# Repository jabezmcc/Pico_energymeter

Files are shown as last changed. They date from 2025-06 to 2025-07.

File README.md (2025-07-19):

## Raspberry Pi Pico-based True Energy Meter for Appliances

This project couples a simple circuit with a Raspberry Pi Pico to capture the voltage and current waveforms of the power supplying any appliance, allowing a true, cycle-averaged measure of the power consumption.

The circuit uses a step-down transformer and a voltage divider to measure the voltage, and an Amploc current sensor to measure the current.  These signals are amplified and offset to the 0 - 3.3 V input range of the Pico ADCs.  Waveform data is captured over 3 cycles of the 60 Hz AC line supply, and the product of these is integrated.  Phase differences (as would happen with a motor), current spikes (within reason), etc, are automatically captured and integrated, so the measured  power is as correct as possible.

The Pico is programmed using MicroPython.  Voltages on the two ADCs are collected, the power is calculated, and the value is sent to an LCD display.  On a command from a host computer connected via USB, either the power value or a full 3-cycle waveform is transmitted for further processing and display.  The host code is written in Python, with a Qt6-based GUI that displays a chart of the power consumption vs. time, as well as numerical displays of the current power, the average power since starting acquisition, and the total energy consumed. 
 
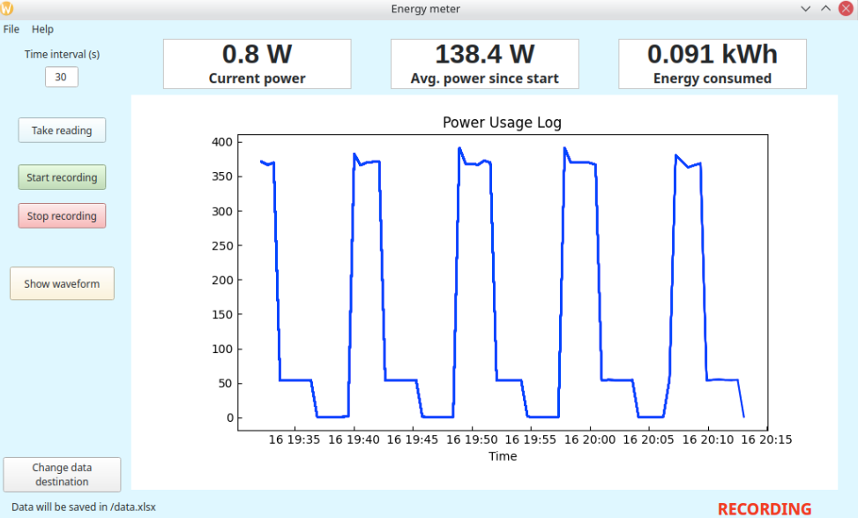
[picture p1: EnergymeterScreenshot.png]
Screenshot of dehumidifier energy consumption over about 40 min


#### Circuit description
AC power comes in via a male power receptacle and flows directly to the appliance via a female power socket. One of the wires carrying current passes through an [Amploc AMP25 current sensor](https://amploc.com/products/amp25-open-loop-hall-effect-sensor), which provides a 1.57 V to 3.42 V signal for currents from -25 A to +25 A.  The AC line voltage is also connected to a small step-down transformer producing 13.6 VAC.  I used something salvaged from an old phone system, but any small transformer that gets you down to below 20 V or so will work. 
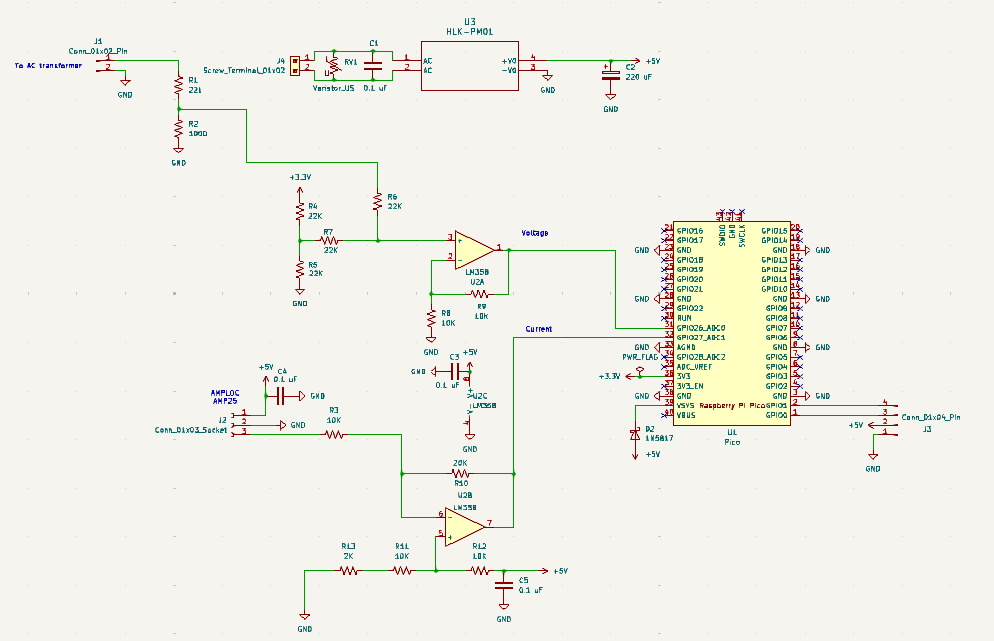
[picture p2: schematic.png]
Schematic of Pico Energymeter circuit

The voltage from the transformer is further divided down and offset using one of the op amps in a LM358 chip, and fed to ADC0 on the Pico.  The AMP25 output is similarly amplified and offset using the other half of the LM358 to match the ADC range, and fed to ADC1 on the Pico.  5 V power for the Pico, the AMP25, and the LM358 is provided by a small HLK-PM01 supply on board.  

#### Construction notes
Most of the circuit is on a circuit board, detailed in this [KiCAD file](./Pico_energymeter_v2.kicad_pro).
  
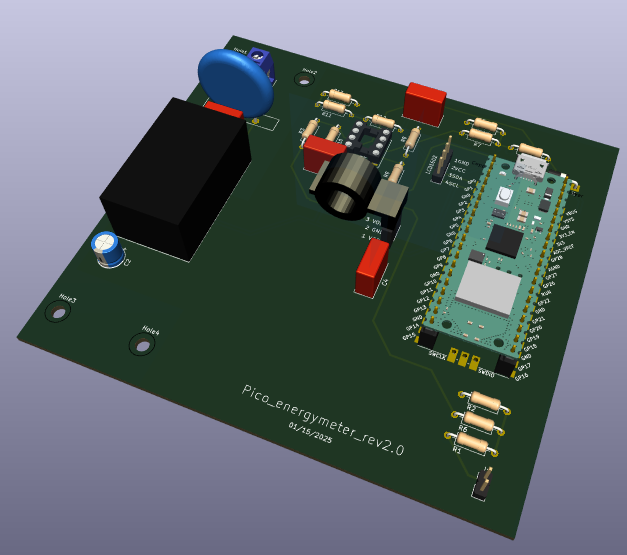
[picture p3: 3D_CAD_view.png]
3D CAD view
  

Everything is mounted in a plastic box, with the LCD 1602 display mounted in the lid. The display mount uses a home-made 3D-printed bezel (step file [here](./LCD1602bezel.step)). A short microUSB extender cable is used to bring the Pico's USB connection to a socket on the box wall.

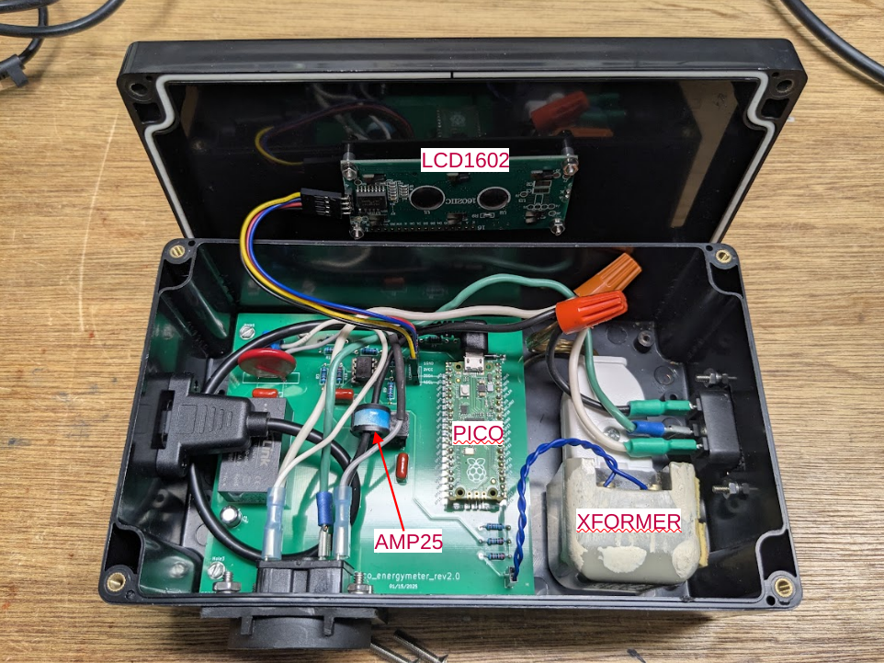
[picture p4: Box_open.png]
Box, open
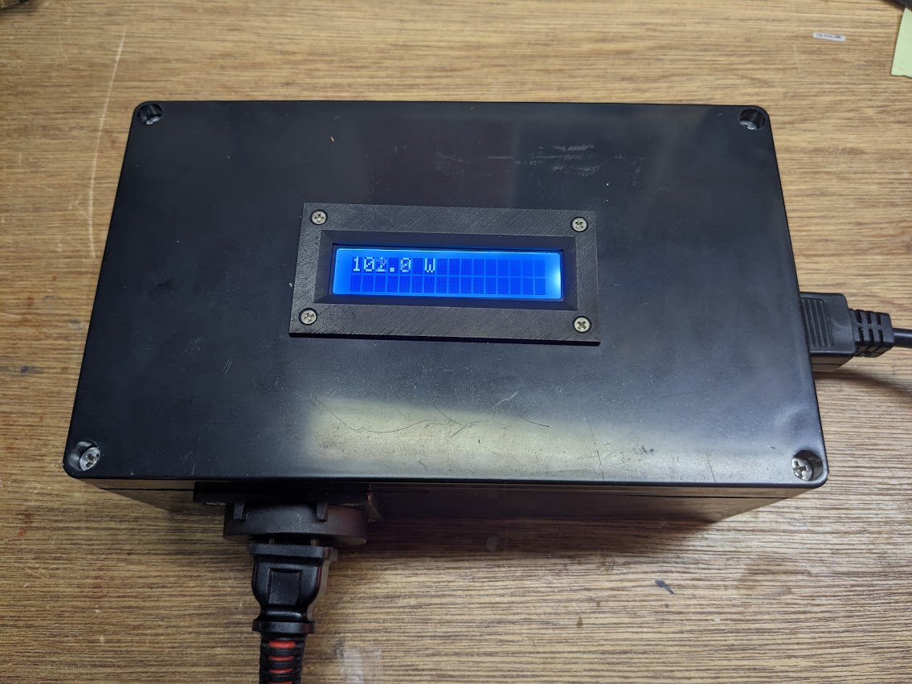
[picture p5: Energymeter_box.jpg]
Bax, closed
  

#### Pico code

The MicroPython code that runs on the Pico is contained in the file `powmon_picocode.py`.  This needs to be saved on the Pico as `main.py`.  The code makes use of a LCD1602 I2C Python library (of which there are many) downloaded from [https://github.com/liyuanhe211/Micropython_LCD1602_LCD2004_I2C_Lib](https://github.com/liyuanhe211/Micropython_LCD1602_LCD2004_I2C_Lib).  The file `lib_lcd1602_2004_with_i2c.py` from that site is included here under the name `lyhlcd1602.py`, and must also be stored on the Pico.  The easiest way to put these files on the Pico is by using [Thonny](https://thonny.org/).  

The code does the usual setup for LED, I2C, etc and sets up arrays for voltage and current measurements with 801 points each.  The nominal time between points for 3 cycles of 60 Hz is 3/60/801 =  62.42 $`\mu`$s.  However, there will be inherent small delays so it is necessary to do a measurement to determine empirically how many $`\mu`$s to tell MicroPython to wait between each point in order to ensure exactly 3 cycles with 801 points.  The procedure for this is described below.  

The main while-loop of the code cycles every 0.1 sec.  On each cycle it reads 801 points from the ADCs and calculates the power by multiplying the voltage and the current and integrating via Simpson's rule. The result is multiplied by a calibration factor determined as described below.  

On each cycle the code also reads two bytes from the USB serial port.  These two bytes represent requests from the host code.  If `b'po'` is transmitted this is a request for a power measurement, and the Pico code sends back a string version of the most recent power measurement.  If `b'wa'` is transmitted this is a request for the waveform, and the Pico code does a fresh measurement of the ADCs, packs the data bytes into a structure using `struct.pack()` and transmits these back to the host via `sys.stdout.buffer.write()`.

#### Host code
The host code `energymeter.py` was developed on a Linux system using Python 3.13.3.  I recommend using `pyenv` to set up a virtual environment specifying this version of Python to run it.  The required libraries are listed in `requirements.txt` and can be installed via `pip install requirements.txt`. The code should be fairly easily ported to Windows or MacOS with a few minor adjustments.  Usage should be pretty self explanatory:  click "Take reading" to get a measure of the power, click "Start recording" to begin logging the power, and click "Stop recording" when you want to stop. You will be asked whether you want to save the data.  Click "Show waveform" if you want to see what the voltage and current waveforms look like, and click "Change data destination" if you want to save the data somewhere other than the default location. 
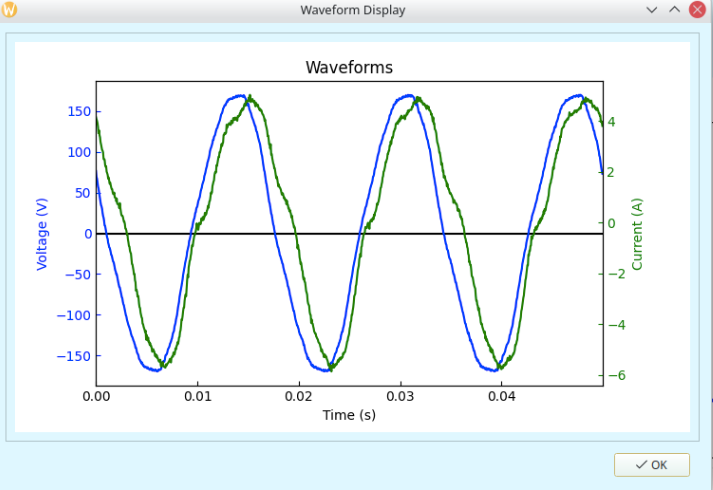
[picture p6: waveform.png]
Screenshot of waveform collected from a dehumidifier with fan and compressor running


#### Set up and Calibration

1. Timing

In order to make sure we get exactly three cycles of 60 Hz when `ndata` points are acquired, we need to find out how long the Pico takes to measure one data point and then add just enough time to equal `3/60/ndata`. This is done with a separate pair of Pico and host programs.  The program `powmon_picocode_get_base_delay.py` is run on the Pico by loading it into Thonny, pressing run, and then exiting Thonny.  Then the host code `Read_pico_find_dt.py` is run on the host computer.  The host code requests a waveform, the Pico code acquires 801 data points without any extra delay between points, and the voltage waveform is uploaded to the host computer.  An optimizer is then run to fit the waveform to a 60 Hz sine wave with the time interval between points, the amplitude and the phase as free parameters. The time interval resulting from this three-parameter fit is the base delay of the Pico.  This is compared to the time interval necessary to get exactly 3 cycles of 60 Hz, and the difference is reported. Measurements on my system indicate a delay of 12 $`\mu`$s  is required, and that is the value that is hard-coded in the main Pico code `powmon_picocode.py`.  If a value different from 12 $`\mu`$s is observed, the main Pico code should be edited and the definition of the constant `delay_us` changed.     

2. Calibration

Because the ADCs in the Pico measure on a scale of 0 to 65535, it is necessary to do an initial measurement to set the correct scaling factor for the voltage, current and power values.  To do this, a 100 W light bulb is plugged into the box and the actual RMS voltage and current are measured with a multimeter. Voltage is read by touching the hot terminals, and current is measured on the 10 A AC scale with the multimeter in the circuit. Of course ***this must be done with great care*** to avoid getting shocked! The light bulb is assumed to be a fully resistive load, so separate measurements of the voltage and current RMS values can be multiplied to obtain the RMS power.  

Once the RMS voltage and current are known for the 100 W light bulb, the correct scaling factors are determined by running another host program, `calibration.py`, on the host while the normal Pico code `powmon_picocode.py` is running on the Pico.  The RMS voltage and current as determined above are entered, then 'Measure' is pressed.  The power is then measured 20 times at 1 second intervals and the average calculated based on whatever scaling value is hard-coded in `powmon_picocode.py`.  The ratio of the actual RMS power to this measured value is reported as a correction factor that needs to be applied to the scaling factor by editing the definition of the constant `powfact` in  `powmon_picocode.py`.

The voltage and current scale factors are obtained by pressing the 'Measure waveform' button.  Three-cycle waveforms for voltage and current  are retrieved from the Pico and least-squares-fit to a sine wave with amplitude and phase as free parameters.  The scale factors necessary to match the amplitudes to $\sqrt2$ times the RMS values are then reported.  The main code `energymeter.py` should then be edited and the constants `voltfact` and  `curfact` set to these values. Note these values are only used when displaying the waveforms.  The power measurement has a separate scale factor stored in the Pico code.

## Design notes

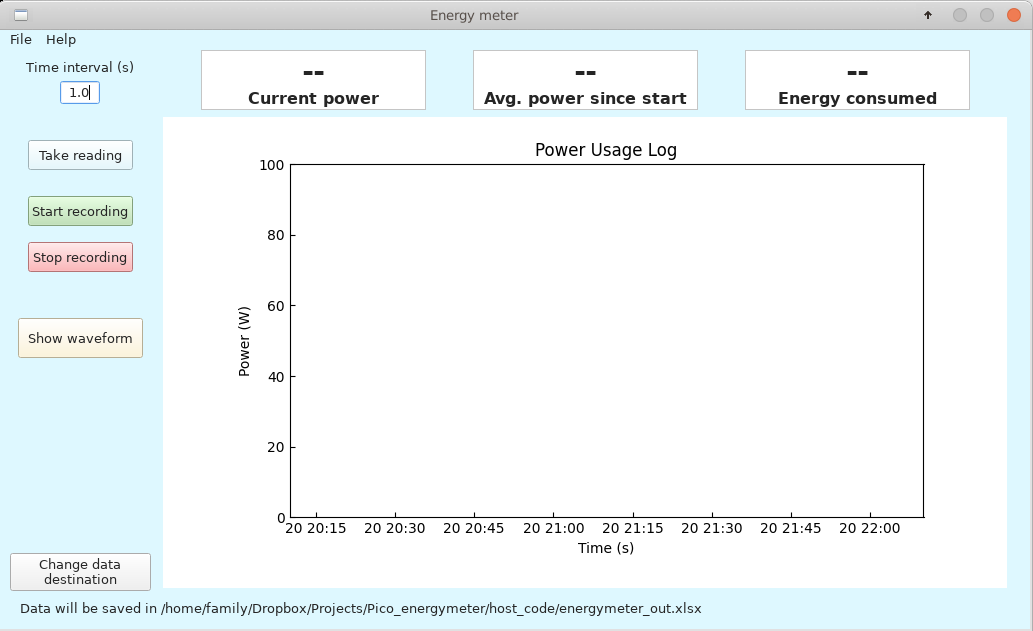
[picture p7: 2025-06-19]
Hostcode_screenshot.png

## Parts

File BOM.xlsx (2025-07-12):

Reference | Value
C1,C3,C4,C5 | 0.1 uF polyester film capacitor or equiv.
C2 | 220 uF electrolytic capacitor
D2 | 1N5817 Schottky diode
J1 | 01x02 male header
J2 | 01x03 female header
J3 | 01x04 male header
J4 | Screw_Terminal_01x02
R1 | 22k resistor
R2 | 1K resistor
R3,R8,R9,R11,R12 | 10K resistor
R4,R5,R6,R7 | 22K resistor
R10 | 20K resistor
R13 | 2K resistor
RV1 | Varistor, 160 V
U1 | Raspberry Pi Pico
U2 | LM358
U3 | HLK-PM01 115VAC to 5VDC power supply
Display | Freenove LCD 1602 display
Current sensor | Amploc AMP25 current sensor
Transformer | Transformer, 13.6 VAC
Cable | microUSB extender, e.g Poyiccot Micro USB Extension Cable, 90 Degree Right Angle Micro USB Male to Micro USB Female Power Extension Panel Mount Type Cable for Data & Charge
Output socket | female AC socket
Input socket | male AC power socket
Box | Junction Box, Zulkit Project Box IP65 Waterproof Outdoor Box ABS Plastic Electrical Boxes Electronic Enclosure Black 7.9 x 4.7 x 2.95 inch (200 x 120 x 75mm)
Bezel | 3D printed per stp file

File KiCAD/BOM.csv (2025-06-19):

Reference | Value | Datasheet | Footprint | Qty | DNP
C1,C3,C4,C5 | 0.1 uF | ~ | Capacitor_THT:C_Rect_L10.3mm_W4.5mm_P7.50mm_MKS4 | 4
C2 | 220 uF | ~ | Capacitor_THT:CP_Radial_D6.3mm_P2.50mm | 1
D2 | 1N5817 | http://www.vishay.com/docs/88525/1n5817.pdf | Diode_THT:D_DO-41_SOD81_P10.16mm_Horizontal | 1
J1 | Conn_01x02_Pin | ~ | Connector_PinHeader_2.54mm:PinHeader_1x02_P2.54mm_Vertical | 1
J2 | Conn_01x03_Socket | ~ | Connector_PinSocket_2.54mm:PinSocket_1x03_P2.54mm_Vertical | 1
J3 | Conn_01x04_Pin | ~ | Connector_PinHeader_2.54mm:PinHeader_1x04_P2.54mm_Vertical | 1
J4 | Screw_Terminal_01x02 | ~ | TerminalBlock:TerminalBlock_bornier-2_P5.08mm | 1
R1 | 22k | ~ | Resistor_THT:R_Axial_DIN0207_L6.3mm_D2.5mm_P10.16mm_Horizontal | 1
R2 | 1000 | ~ | Resistor_THT:R_Axial_DIN0207_L6.3mm_D2.5mm_P10.16mm_Horizontal | 1
R3,R8,R9,R11,R12 | 10K | ~ | Resistor_THT:R_Axial_DIN0207_L6.3mm_D2.5mm_P10.16mm_Horizontal | 5
R4,R5,R6,R7 | 22K | ~ | Resistor_THT:R_Axial_DIN0207_L6.3mm_D2.5mm_P10.16mm_Horizontal | 4
R10 | 20K | ~ | Resistor_THT:R_Axial_DIN0207_L6.3mm_D2.5mm_P10.16mm_Horizontal | 1
R13 | 2K | ~ | Resistor_THT:R_Axial_DIN0207_L6.3mm_D2.5mm_P10.16mm_Horizontal | 1
RV1 | Varistor_US | ~ | Varistor:RV_Disc_D21.5mm_W4.3mm_P10mm | 1
U1 | Pico |  | MCU_RaspberryPi_and_Boards:RPi_Pico_SMD_TH | 1
U2 | LM358 | http://www.ti.com/lit/ds/symlink/lm2904-n.pdf | Package_DIP:DIP-8_W7.62mm_Socket | 1
U3 | HLK-PM01 | HLK-PM01 | HLKPM01:DIP4_HLK-PM_HLK | 1

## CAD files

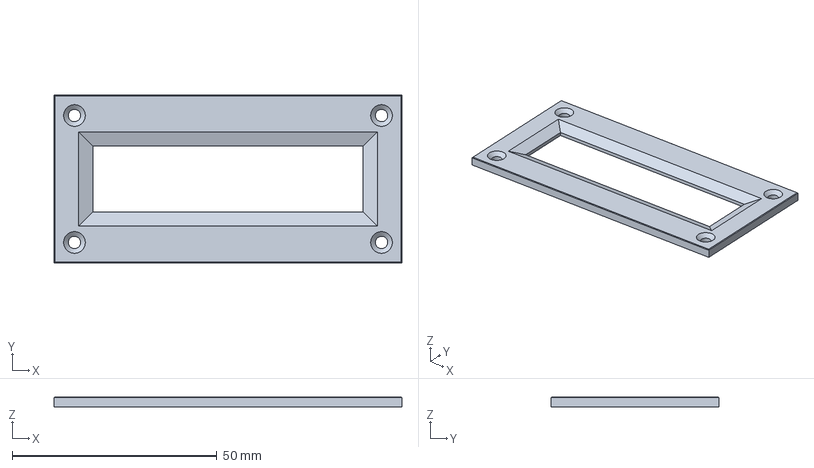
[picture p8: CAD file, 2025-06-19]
LCD1602bezel.step
85.0 x 41.0 x 2.50 mm

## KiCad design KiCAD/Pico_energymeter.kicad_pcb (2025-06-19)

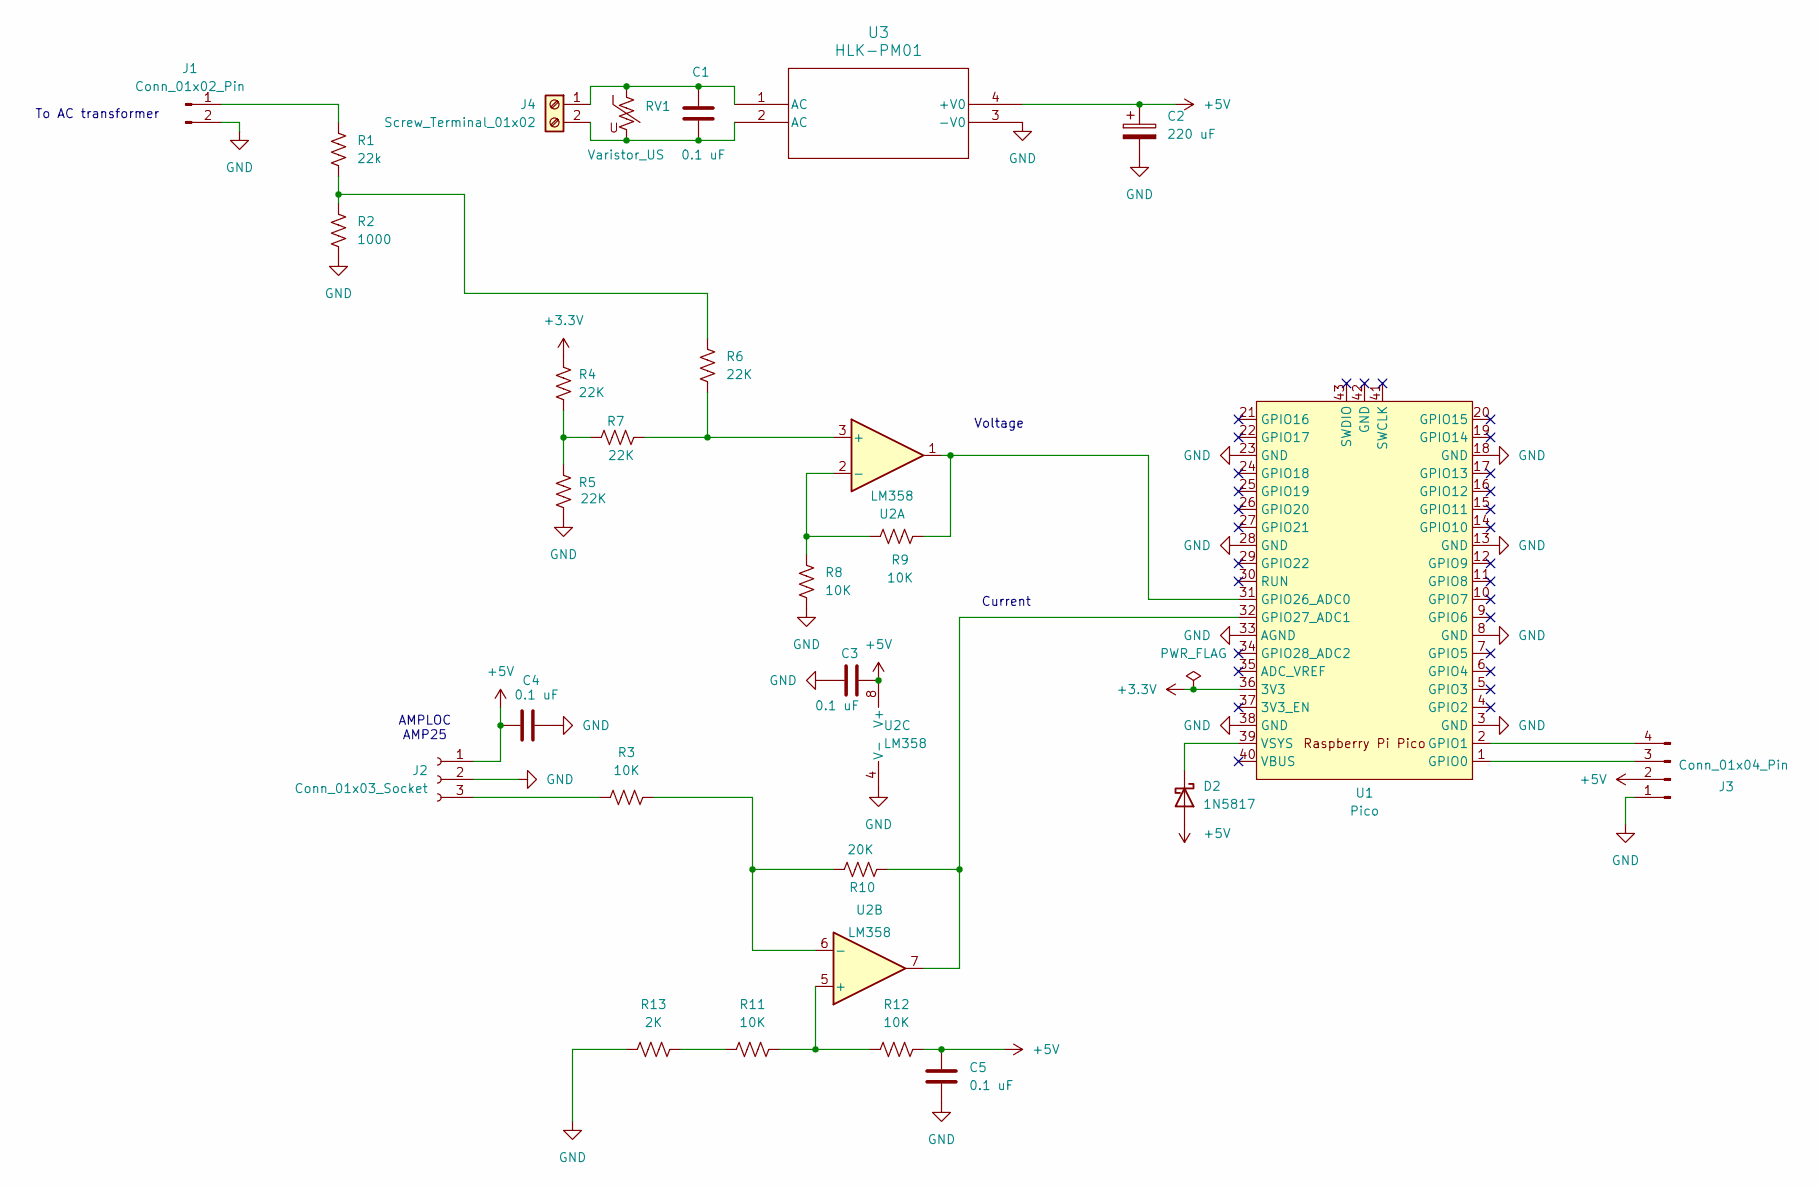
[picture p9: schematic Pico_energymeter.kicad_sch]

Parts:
C1, C3, C4, C5: 0.1 uF; C_Rect_L10.3mm_W4.5mm_P7.50mm_MKS4
C2: 220 uF; CP_Radial_D6.3mm_P2.50mm
D2: 1N5817; D_DO-41_SOD81_P10.16mm_Horizontal
J1: Conn_01x02_Pin; PinHeader_1x02_P2.54mm_Vertical
J2: Conn_01x03_Socket; PinSocket_1x03_P2.54mm_Vertical
J3: Conn_01x04_Pin; PinHeader_1x04_P2.54mm_Vertical
J4: Screw_Terminal_01x02; TerminalBlock_bornier-2_P5.08mm
R1: 22k; R_Axial_DIN0207_L6.3mm_D2.5mm_P10.16mm_Horizontal
R2: 1000; R_Axial_DIN0207_L6.3mm_D2.5mm_P10.16mm_Horizontal
R3, R8, R9, R11, R12: 10K; R_Axial_DIN0207_L6.3mm_D2.5mm_P10.16mm_Horizontal
R4, R5, R6, R7: 22K; R_Axial_DIN0207_L6.3mm_D2.5mm_P10.16mm_Horizontal
R10: 20K; R_Axial_DIN0207_L6.3mm_D2.5mm_P10.16mm_Horizontal
R13: 2K; R_Axial_DIN0207_L6.3mm_D2.5mm_P10.16mm_Horizontal
RV1: Varistor_US; RV_Disc_D21.5mm_W4.3mm_P10mm
U1: Pico; RPi_Pico_SMD_TH
U2: LM358; DIP-8_W7.62mm_Socket
U3: HLK-PM01; DIP4_HLK-PM_HLK

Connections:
+3.3V: R4.1, U1.36 (3V3)
+5V: C2.1, C3.2, C4.1, C5.1, D2.2 (A), J2.1, J3.2, R12.2, U2.8 (V+), U3.4 (+V0)
GND: C2.2, C3.1, C4.2, C5.2, J1.2, J2.2, J3.1, R2.2, R5.2, R8.2, R13.1, U1.3 (GND), U1.8 (GND), U1.13 (GND), U1.18 (GND), U1.23 (GND), U1.28 (GND), U1.33 (AGND), U1.38 (GND), U2.4 (V-), U3.3 (-V0)
unnamed: D2.1 (K), U1.39 (VSYS)
unnamed: J1.1, R1.1
unnamed: J2.3, R3.1
unnamed: J3.3, U1.1 (GPIO0)
unnamed: J3.4, U1.2 (GPIO1)
unnamed: C1.1, J4.1, RV1.1, U3.1 (AC)
unnamed: C1.2, J4.2, RV1.2, U3.2 (AC)
unnamed: R1.2, R2.1, R6.2
unnamed: R4.2, R5.1, R7.1
unnamed: R11.1, R13.2
unnamed: R9.2, U1.31 (GPIO26_ADC0), U2.1
unnamed: R10.2, U1.32 (GPIO27_ADC1), U2.7
unnamed: R6.1, R7.2, U2.3 (+)
unnamed: R8.1, R9.1, U2.2 (-)
unnamed: R11.2, R12.1, U2.5 (+)
unnamed: R3.2, R10.1, U2.6 (-)

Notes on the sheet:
Voltage
To AC transformer
Current
AMPLOC AMP25

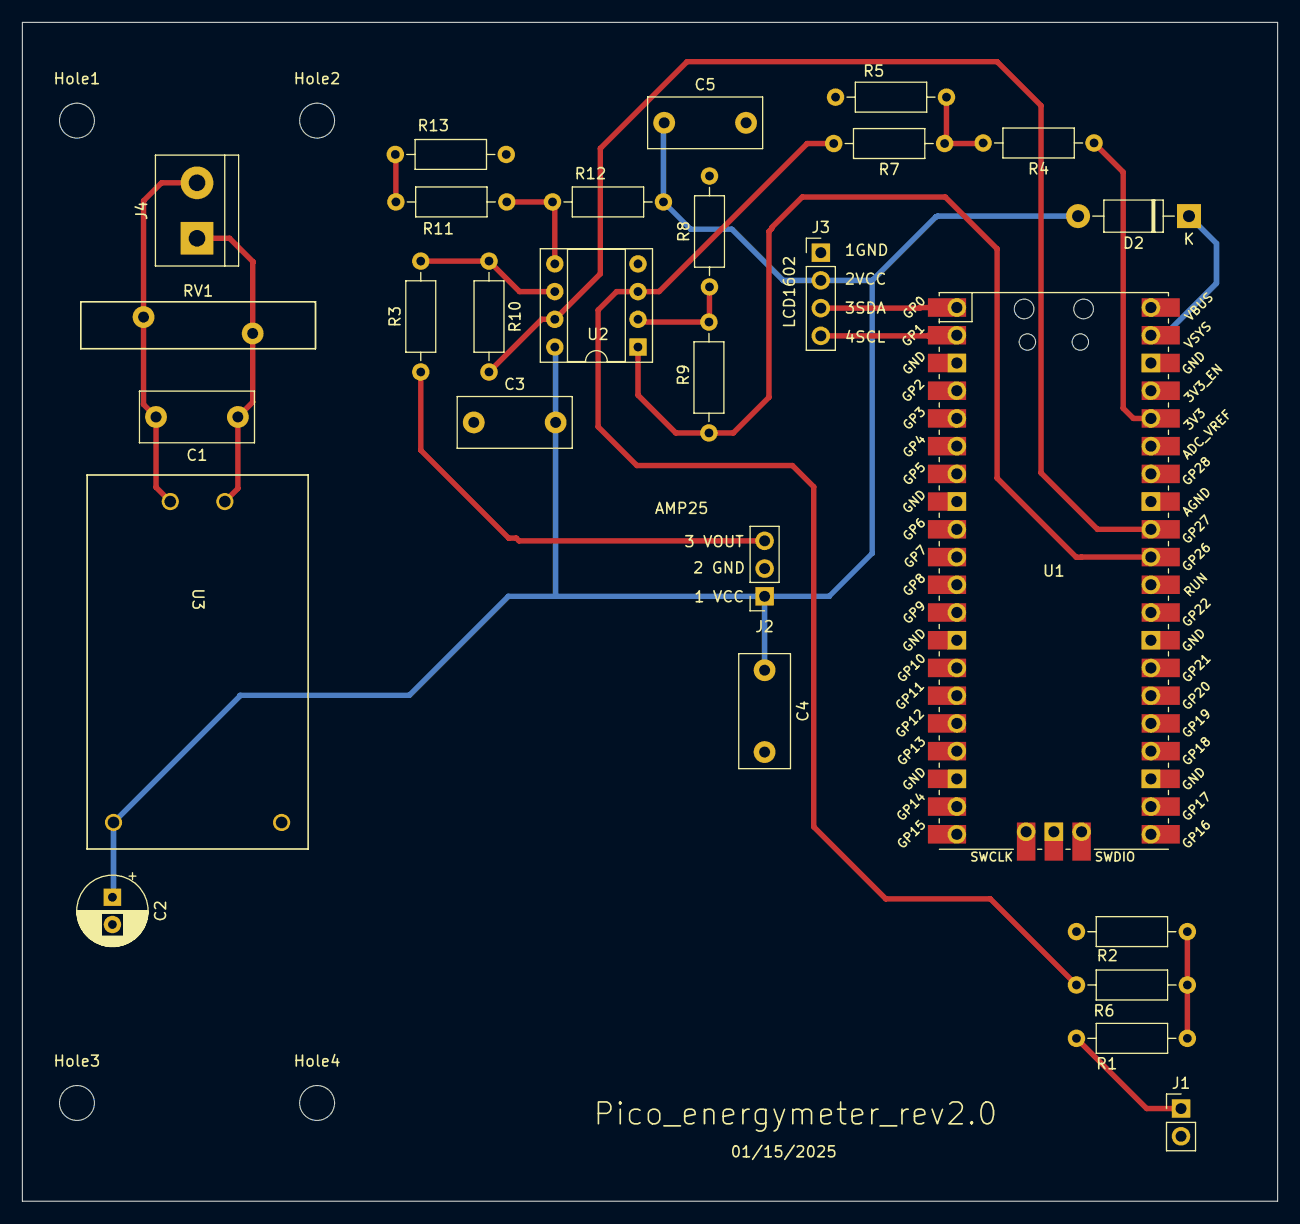
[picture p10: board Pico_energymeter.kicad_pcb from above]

Board: 2 copper layers, 115.0 x 108.0 mm, 31 parts (0 on the bottom side), 19 nets.

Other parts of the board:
Hole1, Hole2, Hole3, Hole4: MountingHole_3.2mm_M3_ISO7380

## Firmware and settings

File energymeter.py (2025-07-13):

'''
Host code for Raspberry Pi Pico energy meter https://github.com/jabezmcc/Pico_energymeter
Jabez McClelland  
6/19/2025 - Version 0.1 
'''
import sys
import os
import xlsxwriter
import datetime as dt
import time
import numpy as np
import subprocess
import platform
import pathlib
import serial
import threading

from PyQt6.QtCore import QObject
from PyQt6.QtWidgets import QApplication, QFileDialog, QMessageBox
from PyQt6.uic import loadUiType

from matplotlib.backends.backend_qt5agg import FigureCanvasQTAgg as FigureCanvas
import matplotlib.pyplot as plt

Ui_MainWindow, QMainWindow = loadUiType('energymeter.ui') 
Ui_WaveformWindow, QWaveformWindow = loadUiType('waveform.ui')
Ui_AboutWindow, QAboutWindow = loadUiType('AboutEnergymeter.ui')
vers = '0.1' 

# Set up communications with Pico.  This is for Linux but is OS dependent so may need adjusting. 
port = "/dev/ttyACM0"
baudrate = 115200
ndata = 801 # number of datapoints for waveform acquisition
ncyc = 3  # number of 60 Hz cycles to acquire
voltfact = 163.69 # calibration factor for voltage
curfact = 12.263 # calibration factor for current


class About(QAboutWindow, Ui_AboutWindow):
    def __init__(self):
        super(About,self).__init__()
        self.setupUi(self)
        self.versionLabel.setText("Version "+vers)
        self.licenseButt.clicked.connect(self.show_license)
        self.OKButt.clicked.connect(self.closeout)
        self.show()

    def show_license(self):
        # This bit should work cross platform
        p = platform.system()
        try:
            if p == 'Linux':
                subprocess.run(['xdg-open', 'LICENSE.txt'],check=True)
            elif p=='Windows':
                os.system('start LICENSE.txt')
            else:
                os.system('open LICENSE.txt')
        except:
             QMessageBox.warning(self,'Error','Unable to open license document')

    def closeout(self):
        self.close()
        
class ShowWaveform(QWaveformWindow,Ui_WaveformWindow):
    def __init__(self,wavedata):  # wavedata is a three-element list of ndata-element lists: time, voltage and current 
        super(ShowWaveform,self).__init__()
        self.setupUi(self)
        Vcolor = 'blue'
        Acolor = 'green'
        self.buttonBox.accepted.connect(self.exit)
        self.canvas = FigureCanvas(plt.Figure())
        self.plotframeLayout.addWidget(self.canvas)
        t = wavedata[0]
        v = wavedata[1]
        cur = wavedata[2]
        self.ax = self.canvas.figure.subplots()
        self.ax2 = self.ax.twinx()
        self.ax.set_xlabel("Time (s)")
        self.ax.set_ylabel("Voltage (V)",color=Vcolor)
        self.ax.tick_params(axis='y', colors=Vcolor)
        self.ax.axhline(y=0,color='black')
        self.ax2.set_ylabel("Current (A)",color=Acolor)       
        self.ax.set_title("Waveforms")
        self.ax.set_position([.12,.12,.75,.78])
        self.ax.tick_params(axis='both',direction='in')
        self.ax2.tick_params(axis='y',direction='in')
        self.ax.set_xlim(t[0],t[-1])        
        self.ax.plot(t,v,color=Vcolor)
        self.ax2.plot(t,cur,color=Acolor)
        self.ax2.tick_params(axis='y', colors=Acolor)
        self.canvas.draw()
        self.canvas.flush_events()
        self.show()

    def exit(self):
        self.destroy()  

class Main(QMainWindow, Ui_MainWindow):
    plotexists = False
    takedata = True
    datasaved = False
    def __init__(self):
        super(Main,self).__init__()
        self.setupUi(self)
        self.actionExitButton.triggered.connect(self.exit)
        self.menuBar.setStyleSheet("QMenu::item::selected {color: rgb(30,30,30);}")
        self.actionAbout.triggered.connect(self.openabout)
        self.takeReading.clicked.connect(self.single_reading)
        self.startButton.clicked.connect(self.start_data)
        self.stopButton.clicked.connect(self.stop_data)
        self.waveformButton.clicked.connect(self.show_waveform)
        cwd = str(pathlib.Path(__file__).parent.resolve())
        self.data_dest = cwd +'/energymeter_out.xlsx'
        self.dataSaveLabel.setText('Data will be saved in '+self.data_dest)
        self.changeDataButton.clicked.connect(self.change_data_dest)
        self.timeintervalBox.setText('1.0')
        self.currentPower.setText('--')
        self.avgPower.setText('--')
        self.kWh.setText('--')
        self.canvas = FigureCanvas(plt.Figure(figsize=(15, 6)))
        self.mainplot_layout.addWidget(self.canvas)
        self.ax = self.canvas.figure.subplots()
        self.ax.set_xlabel("Time (s)")
        self.ax.set_ylabel("Power (W)")       
        self.ax.set_title("Power Usage Log")
        self.ax.set_position([.15,.15,.75,.75])
        self.ax.tick_params(axis='both',direction='in')
        self.ax.set_ylim(0,100)
        self.ax.set_xlim(dt.datetime.now(),dt.datetime.now()+dt.timedelta(hours=2))
        self.rec_label.setText('')
        # Try to connect to Pico.  If it fails, switch to simulation mode
        try:
            self.ser = serial.Serial(port, baudrate, timeout=1)
            self.dummy = False
        except:
            QMessageBox.warning(self,'Energy meter','No measurement module detected, simulating data')
            self.dummy = True 

    def openabout(self):
        self.aboutwin = About()

    def single_reading(self):
        if self.dummy:
            p = 100.0 + np.random.random_sample()
            avpower = '{:.1f}'.format(p)
        else:
            self.ser.write(b'po') # This triggers Pico to send back the measured power. 
            time.sleep(0.5)
            avpower = self.ser.readline().decode('utf-8').strip()
            time.sleep(0.5)
        self.currentPower.setText(avpower+' W')
        return float(avpower)
        
    def start_data(self):
        # Data acquisition is in a separate thread so we can still interact with the gui.
        x = threading.Thread(target=self.take_data, daemon=True)
        x.start()
        
    def take_data(self):
        self.takedata = True
        self.rec_label.setText('RECORDING')  
        self.wb = xlsxwriter.Workbook(self.data_dest)
        wbtimefmt = self.wb.add_format({'num_format': 'mmm d yyyy hh:mm:ss'})
        ws = self.wb.add_worksheet()
        ws.set_column(0,0,20)
        ws.set_column(1,3,15)
        ws.write(0,0,'Time')
        ws.write(0,1,'Power')
        ws.write(0,2,'Avg. Power')
        ws.write(0,3,'Energy')        
        times = []
        powers = []
        avpowers = []
        energies = []
        count = 0
        self.ax.cla()
        self.ax.set_xlabel("Time")
        self.ax.set_title("Power Usage Log")
        deltat = 0.1
        while self.takedata:
            try:
                interval = float(self.timeintervalBox.text())
            except:
                QMessageBox.warning(self,'Error','Invalid entry for time interval')
                break 
            count += 1
            elapsed_time = 0.0
            while elapsed_time < interval:
                time.sleep(deltat)
                QApplication.processEvents()
                if not self.takedata:
                    break
                elapsed_time += deltat
            if not self.takedata:
                break
            current_power = self.single_reading()
            times.append(dt.datetime.now())            
            powers.append(current_power)
            avpowers.append(sum(powers)/len(powers))
            if count == 1:
                energies.append(powers[0]*interval*0.001/3600.) # converting W-s to kWh
            else:
                energies.append(sum(powers)*interval*0.001/3600.) # converting W-s to kWh
            self.currentPower.setText("{:3.1f}".format(current_power)+' W')
            self.avgPower.setText("{:3.1f}".format(avpowers[-1])+' W')
            self.kWh.setText("{:3.3f}".format(energies[-1])+' kWh')
            ws.write(count,0,times[-1],wbtimefmt)
            ws.write(count,1,powers[-1])
            ws.write(count,2,avpowers[-1])
            ws.write(count,3,energies[-1])         
            self.plot_data(data=[times,powers])

    def plot_data(self,data=[[0],[0]]):
#        if self.plotexists:
#            self.lin.remove()
        self.lin, = self.ax.plot(data[0],data[1],color='blue')
#        self.ax.set_ylim(bottom=0)
        self.canvas.draw()
        self.canvas.flush_events()
        self.plotexists = True    
        
    def stop_data(self):
        self.takedata = False
        self.rec_label.setText('')
        qbox = QMessageBox.question(self,'Energy meter','Do you want to save data?',QMessageBox.StandardButton.Yes,QMessageBox.StandardButton.No)
        if self.plotexists:
            if qbox == QMessageBox.StandardButton.Yes:
                self.wb.close()
                self.datasaved = True
                QMessageBox.information(self,'Energy meter','Acquisition finished.\nData saved in'+self.data_dest)
        else:
            QMessageBox.information(self,'Energy meter','Please record some data first.')    

    def show_waveform(self):
        if not self.dummy:     
            self.ser.write(b'wa') # Triggers Pico to send the voltage array, then the current array
        volts = np.empty(ndata)
        amps = np.empty(ndata)
        dt = ncyc/60./ndata
        t = dt*np.arange(ndata)
        if not self.dummy:
            # Read voltage array
            for i in range(ndata):
                result = self.ser.read(2)
                volts[i] = int.from_bytes(result,sys.byteorder)
            time.sleep(0.05)
            # Read current array            
            for i  in range(ndata):
                result = self.ser.read(2)
                amps[i] = int.from_bytes(result,sys.byteorder)
            # Rescale the data
            volts = [voltfact*(float(x) - sum(volts)/ndata)*3.3/65536. for x in volts]
            amps = [-curfact*(float(x) - sum(amps)/ndata)*3.3/65536. for x in amps] # amps needs minus sign because of op amp inversion
        else:
            for i in range(ndata):
                volts[i]  = 169.99*(1 + 2*np.random.random_sample()/10.)*np.sin(2*np.pi*t[i]*60)
                amps[i] = 1.206*(1 + 2*np.random.random_sample()/10.)*np.sin(2*np.pi*t[i]*60)
        wavedata = [t,volts,amps]
        self.wfwindow = ShowWaveform(wavedata)

    def change_data_dest(self):
        fileName, _ = QFileDialog.getSaveFileName(self,"Select data destination file","./","Excel files (*.xlsx)")
        if fileName:
            strfN = str(fileName)
            if strfN[-5:] != '.xlsx':
                strfN = strfN + '.xlsx'
            self.data_dest = strfN
            self.dataSaveLabel.setText('Data will be saved in ' + strfN) 
            
    def exit(self):
        sys.exit()

if __name__=="__main__":
    app = QApplication(sys.argv)
    main = Main()
    main.show()

    sys.exit(app.exec())

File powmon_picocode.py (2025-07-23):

'''
MicroPython code for the Raspberry Pi Pico used for the appliance
energy usage project https://github.com/jabezmcc/Pico_energymeter.
Use this code on the Pico together with energymeter.py on the host computer.
Version 0.1 Jabez McClelland, July 2025

'''


from machine import ADC, Pin, SoftI2C
from lyhlcd1602 import LCD
import time
import sys
import array
import struct
import select

powfact = 5.208e-6  # This is the scale factor determined by running the calibration procedure.  See Readme.md
version = '0.1'

def simpson(signal,dt):
    # integrates signal
    n = len(signal) #n must be odd!
    integral = (dt/3) * (signal[0] + 2*sum(signal[:n-2:2]) \
            + 4*sum(signal[1:n-1:2]) + signal[n-1])
    return integral

def get_power(volts,amps):
    # read ADCs and returns cycle-averaged power as float
    for i in range(ndata):
        volts[i] = adc0.read_u16()
        amps[i] = adc1.read_u16()
        time.sleep_us(delay_us)
    # calculate average power
    avvolts = sum(volts)/ndata
    avamps = sum(amps)/ndata
    volts = [(float(x) - avvolts) for x in volts]
    amps = [(float(x) - avamps) for x in amps]
    power = [x*y for x,y in zip(volts,amps)]
    return -powfact*simpson(power,dt)*60/ncyc

# set up LED
led = Pin(25, Pin.OUT)

# Set up 1602 LCD deisplay
lcd = LCD(SoftI2C(scl=Pin(1), sda=Pin(0), freq=100000))
lcd.puts("Powermeter "+version)
time.sleep_ms(4000)
lcd.puts('                ')

# Set up ADCs
adc0 = ADC(26)
adc1 = ADC(27)

spoll = select.poll()
spoll.register(sys.stdin, select.POLLIN)

# Set up parameters
ndata = 801
ncyc = 3
dt = ncyc/60./ndata
delay_us = 12 # Extra delay needed on top of base delay as determined by Read_pico_find_dt.py 
volts = array.array('i', 0 for i in range(ndata))
amps = array.array('i', 0 for i in range(ndata))
nexpav = 10 # Reduces noise in LCD readout
expav_pow = get_power(volts,amps)
count = 0
while True:
    count += 1
    # Read data first to minimize delays
    power = get_power(volts,amps)
    expav_pow = power*2/(nexpav + 1) + expav_pow*(1 - 2/(nexpav +1)) 
    powerstring = '{:.1f}'.format(expav_pow)
    if count == 10:
        lcd.puts(powerstring+' W      ')
        count = 0
    if spoll.poll(10):
        led.value(1)
        instring = sys.stdin.buffer.read(2)       
        if instring == b'po': # Request was for a power reading
            print(powerstring)
        elif instring == b'wa': # Request was for a wafeform
            for i in range(ndata):
                volts[i] = adc0.read_u16()
                amps[i] = adc1.read_u16()
                time.sleep_us(delay_us)
            for i in range(ndata):    
                bnum = struct.pack('H',volts[i])
                sys.stdout.buffer.write(bnum)
            time.sleep(0.05)
            for i in range(ndata):
                bnum = struct.pack('H',amps[i])
                sys.stdout.buffer.write(bnum) 
        led.value(0)
    time.sleep(0.1)
        

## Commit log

2025-06-19 commit more files
    [BOM.csv, BOM.xlsx, LCD1602bezel.step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]
2025-07-12 updated BOM
    [BOM.xlsx]
2025-07-13 code cleanup
    [energymeter_out.xlsx]
2025-07-29 correct schematic
    [Pico_energymeter.kicad_sch]
